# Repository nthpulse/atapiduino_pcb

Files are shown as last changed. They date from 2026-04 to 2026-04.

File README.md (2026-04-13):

# atapiduino_pcb
PCB for Carlos Durandal's Atapiduino project

Gerbers are in the atapiduino.zip file.

All credit for the original project, schematics and firmware goes to Carlos Durandal:
http://singlevalve.web.fc2.com/Atapiduino/atapiduino.htm

All I did was make this PCB for the project.

http://nthpulse.net/projects/atapiduino_pcb

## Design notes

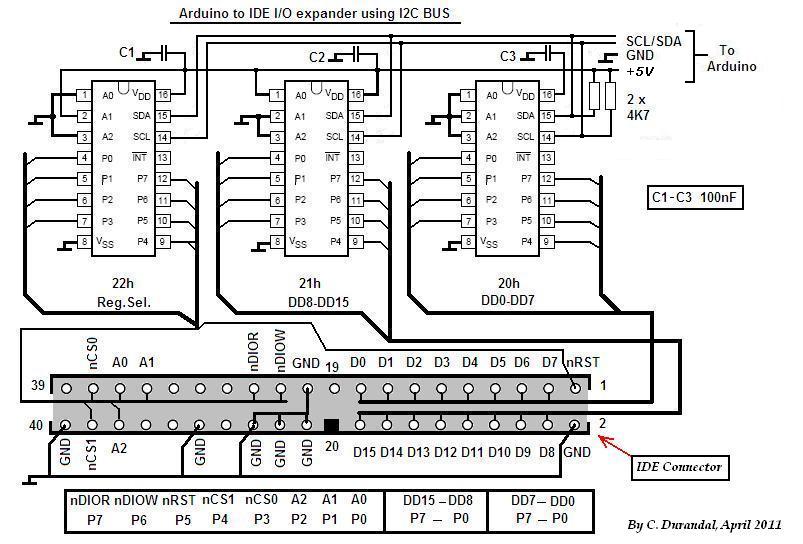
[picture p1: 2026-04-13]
io_exp_2_IDE.jpg

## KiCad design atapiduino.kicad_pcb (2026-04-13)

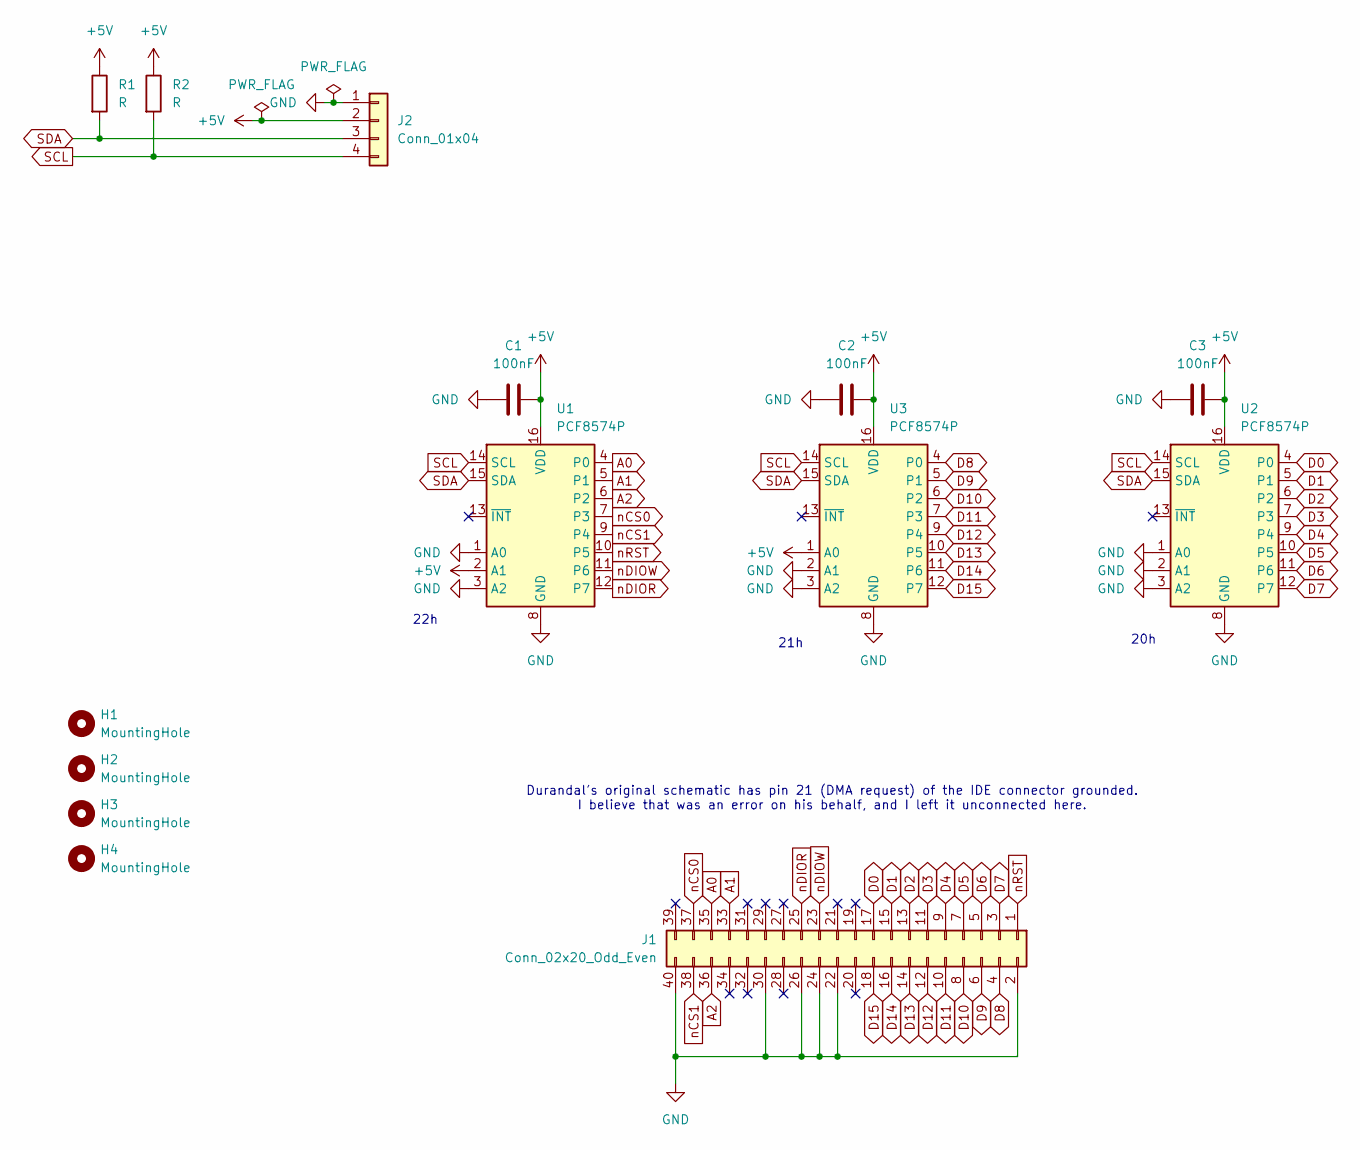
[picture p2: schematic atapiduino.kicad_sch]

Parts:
C1, C2, C3: 100nF; C_Disc_D3.0mm_W1.6mm_P2.50mm
H1, H2, H3, H4: MountingHole; MountingHole_3.2mm_M3
J1: Conn_02x20_Odd_Even; IDC-Header_2x20_P2.54mm_Vertical
J2: Conn_01x04; PinHeader_1x04_P2.54mm_Vertical
R1, R2: R; R_Axial_DIN0207_L6.3mm_D2.5mm_P10.16mm_Horizontal
U1, U2, U3: PCF8574P; DIP-16_W7.62mm

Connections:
+5V: C1.1, C2.1, C3.1, J2.2, R1.1, R2.1, U1.2 (A1), U1.16 (VDD), U2.16 (VDD), U3.1 (A0), U3.16 (VDD)
A0: J1.35, U1.4 (P0)
A1: J1.33, U1.5 (P1)
A2: J1.36, U1.6 (P2)
D0: J1.17, U2.4 (P0)
D1: J1.15, U2.5 (P1)
D2: J1.13, U2.6 (P2)
D3: J1.11, U2.7 (P3)
D4: J1.9, U2.9 (P4)
D5: J1.7, U2.10 (P5)
D6: J1.5, U2.11 (P6)
D7: J1.3, U2.12 (P7)
D8: J1.4, U3.4 (P0)
D9: J1.6, U3.5 (P1)
D10: J1.8, U3.6 (P2)
D11: J1.10, U3.7 (P3)
D12: J1.12, U3.9 (P4)
D13: J1.14, U3.10 (P5)
D14: J1.16, U3.11 (P6)
D15: J1.18, U3.12 (P7)
GND: C1.2, C2.2, C3.2, J1.2, J1.22, J1.24, J1.26, J1.30, J1.40, J2.1, U1.1 (A0), U1.3 (A2), U1.8 (GND), U2.1 (A0), U2.2 (A1), U2.3 (A2), U2.8 (GND), U3.2 (A1), U3.3 (A2), U3.8 (GND)
SCL: J2.4, R2.2, U1.14 (SCL), U2.14 (SCL), U3.14 (SCL)
SDA: J2.3, R1.2, U1.15 (SDA), U2.15 (SDA), U3.15 (SDA)
nCS0: J1.37, U1.7 (P3)
nCS1: J1.38, U1.9 (P4)
nDIOR: J1.25, U1.12 (P7)
nDIOW: J1.23, U1.11 (P6)
nRST: J1.1, U1.10 (P5)

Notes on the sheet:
Durandal's original schematic has pin 21 (DMA request) of the IDE connector grounded. I believe that was an error on his behalf, and I left it unconnected here.
21h
20h
22h

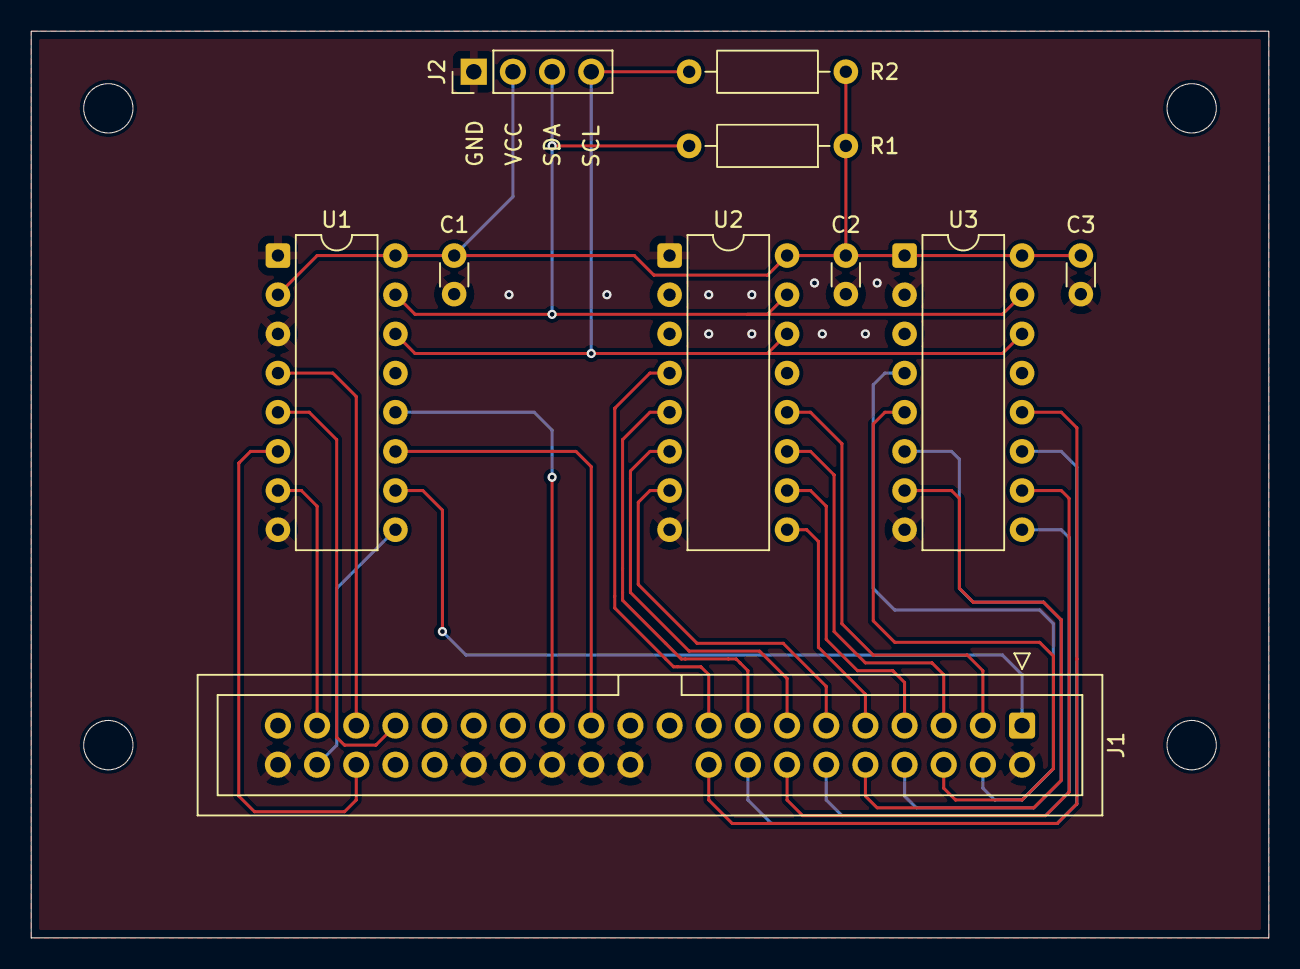
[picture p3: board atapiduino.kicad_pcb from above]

Board: 2 copper layers, 80.3 x 58.8 mm, 14 parts (0 on the bottom side), 28 nets.
